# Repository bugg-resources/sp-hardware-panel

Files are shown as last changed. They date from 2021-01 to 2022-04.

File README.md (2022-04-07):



# sp-hardware-panel

This repository contains the KiCad source files for the panelled version of the PCBs required for the Bugg recording device (``main``, ``led``, and ``mic``). 

Also hosted here is the itemised BoM for the whole project.

For a full overview of the design of the Bugg recording device and practical assembly instructions please refer to the [Bugg hardware handover document](https://raw.githubusercontent.com/bugg-resources/bugg-handover/master/bugg-handover.pdf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).

Bugg PCBs panelled together

## Electronics overview

Bugg full assembly - side

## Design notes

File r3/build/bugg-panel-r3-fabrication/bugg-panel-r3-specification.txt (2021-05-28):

Panel
-----
Design stepped 4-up with 5mm borders for machine handling.
Please note the marked area where no mouse bites or supports may be present.
Please provide panel design for review before fabrication.

Quantity: 20 panels (80 units).

PCB specification
-----------------
Material: 4-layer, 1.6mm, 35um copper, FR4.
Stack-up not critical - example could be:
1-2  0.22mm
2-3  1.00mm
3-4  0.22mm
Soldermask: matte black preferred, gloss black ok.
Silkscreen: white, top side only.
Finish: ENIG

Layer order
-----------
F.Cu - top side
In1.Cu - inner 1 (gnd)
In2.Cu - inner 2
B.Cu - bottom side

Contact
-------
Invoice to:
Jeff Gough
Monad Gottfried Ltd.
3 Essex Park Mews, London
purchase@monad.is
+447903005844

Delivery to:
Likely direct to HCD. To be confirmed.

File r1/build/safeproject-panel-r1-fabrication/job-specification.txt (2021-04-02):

Project
-------
safeproject-panel-r1

PCB specification
-----------------
Material: 2-layer, 1.6mm, FR4, ENIG or other planar finish
Soldermask: white preferred, or green if it's quicker
Silkscreen: black / white, top side only

Mechanical
----------
Feel free to add extra framing if the mousebites are too flimsy

Stack-up
--------
F.Cu - top side
B.Cu - bottom side

Assembly
--------
none

Contact
-------
Invoice to:
Jeff Gough
Monad Gottfried Ltd.
3 Essex Park Mews, London
purchase@monad.is
+447903005844

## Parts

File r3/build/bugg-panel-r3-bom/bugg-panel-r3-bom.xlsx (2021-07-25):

Designator | Package | Qty/PCBA | Value | Rating | Manufacturer | MPN | Mouser | Digikey | Farnell | RS | LCSC | Re-reel: M/D/no | Min Qty | Qty to order | Rcvd.prod | Pkg | Unit GBP/100 | Line GBP | Status / best bet | Select source | Description | Substitute | Notes
BT1 | Keystone-3000-CR1220-CR1216 | 1 | CR1220 |  | Keystone | 3000TR | 534-3000TR | 36-3000CT-ND |  |  |  |  | 85 | 100 | 100 |  |  |  |  | M
C105,C101,C107,C111,C109 | C_0402_1005Metric | 5 | 100nF | 6.3V | Murata | GRM155R71H104KE4D | 81-GRM155R71H104KE4D |  |  |  | C1525 |  | 425 | 500 | 500 |  |  |  |  | L
C103,C102,C106 | C_0402_1005Metric | 3 | 1uF | 6.3V | Murata | GRM155C81C105KE5D | 81-GRM155C81C105KE5D |  |  |  | C107372 |  | 255 | 500 | 500 |  |  |  |  | L
C104,C108,C110 | C_0603_1608Metric | 3 | 10uF | 6.3V | Samsung | CL10A106MQ8NNNC | 187-CL10A106MQ8NNNC |  |  |  | C1691 |  | 255 | 1000 | 1000 |  |  |  |  | L
C11 | C_0603_1608Metric | 1 | 18pF |  | Samsung | CL10C180JB8NNNC | 187-CL10C180JB8NNNC |  |  |  | C1647 |  | 85 | 500 | 500 |  |  |  |  | L
C12,C21 | C_0603_1608Metric | 2 | 15pF |  | Samsung | CL10C150JB8NNNC | 187-CL10C150JB8NNNC |  |  |  | C1644 |  | 170 | 500 | 600 |  |  |  |  | L
C13,C16,C15,C14 | C_1206_3216Metric | 4 | 47uF | 6.3V | Murata | GRM31CE70J476ME5L | 81-GRM31CE70J476ME5L |  | 1907351 |  |  |  | 340 | 400 | 500
C20,C19 | C_0402_1005Metric | 2 | DNP |  |  |  |  |  |  |  |  |  | 0 | 0
C23,C22,C29 | C_0805_2012Metric | 3 | 47uF | 6.3V | Samsung | CL21A476MQYNNNE | 187-CL21A476MQYNNNE |  |  |  | C16780 |  | 255 | 500 | 500 |  |  |  |  | L
C24 | C_0805_2012Metric | 1 | DNP 4.7uF |  |  |  |  |  |  |  |  |  | 0
C28 | C_0603_1608Metric | 1 | 1nF |  | Samsung | CL10B102KC8NNNC | 187-CL10B102KC8NNNC |  |  |  | C153291 |  | 85 | 500 | 500 |  |  |  |  | L
C36,C18,C17,C38,C30,C10,C32,C35,C9,C33,C39,C26,C34,C37 | C_0603_1608Metric | 14 | 100nF |  | Samsung | CL10B104KB8NNNC | sub: 187-CL10B104KB85PNL |  |  |  | C1591 |  | 1190 | 4000 | 4000 |  |  |  |  | L
C42,C41,C4,C3,C1 | C_0603_1608Metric | 5 | 220nF | 50V | Samsung | CL10B224KB8NNNC | 187-CL10B224KB8NNNC |  |  |  | C64705 |  | 425 | 600 | 700 |  |  |  |  | L
C112,C40,C7,C31,C8 | C_0603_1608Metric | 5 | 1uF |  | Samsung | CL10B105KO8NNNC | sub:187-CL10B105KO8VPNC |  |  |  | C59782 |  | 425 | 1000 | 1000 |  |  |  |  | L
C43,C45,C6,C5,C2,C44 | C_1206_3216Metric | 6 | 4.7uF | 50V | Samsung | CL31B475KBHNNNE |  |  |  |  | C51205 |  | 510 | 700 | 700 |  |  |  |  | L
D1 | CHIPLED-0805 | 1 | LG R971-KN-1 |  | Osram | LGR971-KN-1 | 720-LGR971-KN-1 | 475-1410-6-ND |  |  |  | DM | 85 | 100 | 100 |  | 0.05 |  | Stock OK | M
D2 | CHIPLED-0805 | 1 | LH R974-LP-1 |  | Osram | LHR974-LP-1 | 720-LHR974-LP-1 | 475-1415-6-ND |  |  |  | DM | 85 | 100 | 100 | reel | 0.05 |  | Stock OK | M
D3 | CHIPLED-0805 | 1 | LO R976-PS-1 |  | Osram | LOR976-PS-1 | 720-LOR976-PS-1 | 475-2488-6-ND |  |  |  | DM | 85 | 100 | 100 | reel | 0.05 |  | Stock OK | M
D4 | D_SOD-123 | 1 | ATV02W360B-HF |  | Comchip | ATV02W360B-HF | 750-ATV02W360B-HF | 641-1664-6-ND |  |  |  | DM | 85 | 100 | 100 |  | 0.127 |  | Stock OK | M
D5 | D_SOD-123F | 1 | 12V |  | Diodes Inc. | BZT52C12-13-F | 621-BZT52C12-13-F | BZT52C1213-FDIDKR-ND |  |  |  | DM | 85 | 100 | 100 |  | 0.05 |  | Stock OK | M
D7 | CHIPLED-0805 | 1 | LY R976-PS-36 |  | Osram | LYR976-PS-36 | 720-LYR976-PS-36 | 475-2560-6-ND |  |  |  | DM | 85 | 100 | 100 |  | 0.05 |  | Stock OK | M
D6,D9 | D_0402_1005Metric | 2 | 0402ESDA-MLP1 |  | Eaton | 0402ESDA-MLP1 | 504-0402ESDA-MLP1 | 283-2964-6-ND |  |  |  | DM | 170 | 200 | 200 | reel | 0.12 |  | Stock OK | M
FB1,FB2 | L_1008_2520Metric | 2 | 1uH |  | Murata | LQM2HPN1R0MJHL | 81-LQM2HPN1R0MJHL | 490-12068-6-ND |  |  |  | DM | 170 | 200 | 200 | reel | 0.16 |  | Stock OK | M
J10 | Molex_CLIK-Mate_502443-0570_1x05-1MP_P2.00mm_Vertical | 1 | 502443-0560 |  | Molex | 502443-0560 | 538-502443-0560 |  |  |  |  |  | 85 | 85 | 85 |  |  |  |  | M
J101 | PinHeader_2x04_P2.00mm_Vertical_SMD_AMPMODU | 1 | 2842142-4 |  | TE | 2842142-4 | 571-2842142-4 | 17-2842142-4TR-ND |  |  |  | no | 85 | 100 | 100 | tape | 0.65 |  | Stock OK | M
J11 | SMA_Amphenol_132134-10_Vertical | 1 | DNP SMA |  | Amphenol | 132134-10 | 523-132134-10 | ARF2755-ND |  |  |  | bulk only | 0 | 0 |  |  | 4.62 |  | Stock OK | D | Fit only on test units
J12 | Coax_Conn_U.FL | 1 | U_FL-R-SMT-1_10_ |  | Cinch Johnson | 128-0711-201 | 530-1280711201 | J983DKR-ND |  |  |  | DM | 85 | 100 | 100 | reel | 0.29 |  | Stock OK | M
J13 | JAE_SIM_Card_SF72S006 | 1 | JAE_SIM_Card_SF72S006 |  | JAE | SF72S006VBDR2500 | 656-SF72S006VBDR2500 | 670-2967-6-ND |  |  |  | DM | 85 | 30 | 90 | reel | 1.07 |  | Stock OK | D | Memory Card Connectors NANO SIM Card |  | 60 in hand
J14 | microSD_JAE_ST11S008V4H | 1 | Micro_SD_Card_Det_JAE_ST11 |  | JAE | ST11S008V4HR2000 | 656-ST11S008V4HR2000 | 670-2695-6-ND |  |  |  | DM | 85 | 85 | 85 | reel | 1.37 |  | Stock OK | D | Memory Card Connectors microSD PUSH-PUSH HIGH RETENTION LOCK
J15 | USB_Micro-B_Amphenol_10118194_Horizontal | 1 | 10118194 |  | Amphenol | 10118194-0001LF | 649-10118194-0001LF | 609-4618-6-ND |  |  |  | DM | 85 | 100 | 100 | reel | 0.21 |  | Stock Med | M
J202,J16 | Hirose_FH12-20S-0.5SH_1x20-1MP_P0.50mm_Horizontal | 2 | FH12A-20S-0.5SH |  | Hirose | FH12A-20S-0.5SH(55) | 798-FH12A-20S0.5SH55 | HFK120CT-ND |  |  |  | DM | 170 | 170 | 170 | reel | 0.84 |  | Stock OK | D
J201 | PinSocket_2x04_P2.00mm_Vertical_SMD_Bottom_or_Top_Entry_AMPMODU | 1 | 2314844-8 |  | TE | 2314844-8 | 571-2314844-8 | 17-2314844-8-ND |  |  |  | tube only | 85 | 85 | 85 | tube | 0.42 |  | Stock OK | D | 8 Position Receptacle, Bottom or Top Entry Connector 0.079" (2.00mm) Surface Mount Gold
L1 | L_Coilcraft_XAL5030 | 1 | 4.7uH |  | Coilcraft | XAL5030-472 | 994-XAL5030-472MEB | no |  |  |  | M | 85 | 100 | 100 | reel | 1.45 |  | Stock OK | M | Fixed Inductors 4.7uH Shld 20% 5.9A 36mOhms AECQ2
L2 | L_Coilcraft_XAL5030 | 1 | 3.3uH |  | Coilcraft | XAL5030-332 | 994-XAL5030-332MEB | no |  |  |  | M | 85 | 100 | 100 | reel | 1.45 |  | Stock OK | M | Fixed Inductors 3.3uH Shld 20% 8.1A 23.3mOhms AECQ2
LED203,LED202,LED201 | LED_Avago_PLCC4_3.2x2.8mm_CW | 3 | IN-P32TATRGB |  | Inolux | IN-P32TATRGB | 743-IN-P32TATRGB | 1830-1116-6-ND |  |  |  | DM | 255 | 260 | 260 | reel | 0.13 |  | Stock OK | M
MIC101 | Knowles_LGA-5_3.5x2.65mm | 1 | SPH0641LU4H-1 |  | Knowles | SPH0641LU4H-1 | 721-SPH0641LU4H-1 | SPH0641LU4H-1 |  |  |  | no stock | 80 |  | 82 |  | 0.98 |  | 82 in hand |  | MEMS Microphones DIG MEMs Mic, BP, Multimode,Ultrasonic
Module1 | Raspberry-Pi-4-Compute-Module-no-holes | 1 | ComputeModule4-CM4 |  | Raspberry Pi | CM4002016 |  |  | 3563481 |  |  |  | 70 | 70 | 70 | bulk | 31.01
Module1_connectors | DF40HC(3.0)-100DS-0.4v | 2 | DF40HC(3.0)-100DS-0.4v |  | Hirose | DF40HC(3.0)-100DS-0.4v | 798-DF40HC30100DS451 | H124602DKR-ND |  |  |  | DM | 170 | 170 | 170 |  | 1.52 |  | Stock OK | M
Q3,Q1,Q2 | Vishay_PowerPAK_1212-8_Single | 3 | Si7113ADN |  | Vishay | SI7113ADN-T1-GE3 | 78-SI7113ADN-T1-GE3 | SI7113ADN-T1-GE3DKR-ND |  |  |  | DM | 255 | 260 | 260 |  | 0.34 |  | Stock OK | M
Q11,Q9,Q4,Q10,Q8,Q7,Q6,Q5 | SOT-323_SC-70 | 8 | NX3008NBKW |  | Nexperia | NX3008NBKW,115 | 771-NX3008NBKW,115 | 1727-1280-6-ND |  |  |  | DM | 680 | 720 | 720 |  | 0.067 |  | Stock OK | M
R101,R102 | R_0402_1005Metric | 2 | 22R |  | Walsin | WR04X22R0FTL | 603-RC0402FR-0722RL |  |  |  | C163821 |  | 170 |  | 5000 |  |  |  |  | L
R18 | R_0402_1005Metric | 1 | DNP |  |  |  |  |  |  |  |  |  | 0 |  |  |  |  |  |  | DNP
R20,R19 | R_0402_1005Metric | 2 | 0R |  | Walsin | WR04X0000FTL | 603-RC0402JR-070RL |  |  |  | C163803 |  | 170 | 1000 | 1000 |  |  |  |  | L
R10,R9 | R_0603_1608Metric | 2 | 1M |  | Walsin | WR06X1004FTL | 603-RC0603FR-071ML |  |  |  | C163869 |  | 170 | 5000 | 5000 |  |  |  |  | L
R7,R8,R16,R13,R14,R12,R24,R11,R103 | R_0603_1608Metric | 9 | 100k |  | Walsin | WR06X1003FTL | 603-RC0603FR-07100KL |  |  |  | C132374 |  | 765 | 5000 | 5000 |  | 0.000869 |  |  | L
R17 | R_0603_1608Metric | 1 | 37.4k |  | Yageo | RC0603FR-0737K4L | RC0603FR-0737K4L |  |  |  | C163425 |  | 85 | 5000 | 5000 |  |  |  |  | L
R2,R3,R1 | R_0603_1608Metric | 3 | DNP |  |  |  |  |  |  |  |  |  | 0 | 0 |  |  |  |  |  | DNP
R201, R202, R203 | R_0603_1608Metric | 3 | 22k |  | RS PRO |  |  |  |  | 804-8952 |  |  | 255 | 5000 | 5000 |  |  |  |  | L | Decide on value for required LED brightness
R204, R205, R206 | R_0603_1608Metric | 3 | 39k |  | Yageo | AC0603FR-0739KL |  |  |  | 197-8062 |  |  | 255 | 5000 | 5000
R22 | R_0603_1608Metric | 0 | DNP 15k |  |  |  |  |  |  |  |  |  | 0 |  |  |  |  |  |  | DNP
R23 | R_0603_1608Metric | 1 | 0R |  | Walsin | WR06X0000FTL | 603-RC0603JR-070RL |  |  |  | C163836 |  | 85 | 5000 | 5000 |  |  |  |  | L
R26,R15,R27,R25 | R_0603_1608Metric | 4 | 23.7k |  | Walsin | WR06X2372FTL | 603-RC0603FR-0723K7L |  |  |  | C168293 |  | 340 | 5000 | 5000 |  |  |  |  | L
R30,R29 | R_0603_1608Metric | 2 | 510k |  | Walsin | WR06X5103FTL | 603-RC0603FR-07510KL |  |  |  | C163930 |  | 170 | 5000 | 5000 |  |  |  |  | L
R35,R36 | R_0603_1608Metric | 2 | 0.1R |  | Uni-Royal | 0603WAJ010KT5E | 603-RL0805JR070R1L |  |  |  | C247025 |  | 170 | 5000 | 5000 |  |  |  |  | L
R44,R5,R4,R34,R28,R31,R32 | R_0603_1608Metric | 7 | 1k |  | Walsin | WR06X1001FTL | 603-RC0603FR-071KL |  |  |  | C112433 |  | 595 | 5000 | 5000 |  |  |  |  | L
R43,R40,R38,R33,R45,R37,R6,R21,R41,R39,R42,R46, R207, R208, R209 | R_0603_1608Metric | 15 | 10k |  | Yageo | 603-RC0603FR-1310KL | 603-RC0603FR-1310KL |  |  |  |  |  | 1275 | 2000 | 2500 |  |  |  |  | M
H101,H102 | Mounting_Wuerth_WA-SMSI-M3_H7mm_9774070360 | 2 | wurth-spacer-WA-SMSI-9774070360 |  | Wurth | 9774070360R | 710-9774070360R | 732-5274-1-ND |  |  |  | Not worth it | 170 | 170 | 169 | reel |  |  | Dk:69 Fn: 51 Sample:30! | DFW
SP3,SP1,SP2,SP4 | wurth-spacer-WA-SMSI-9774030151R | 4 | wurth-spacer-9774030151R |  | Wurth | 9774030151R | 710-9774030151R | 732-7083-6-ND |  |  |  | DM | 340 | 340 | 372 | reel | 0.53 |  | Stock OK | D
U14,U1 | SOT-353_SC-70-5 | 2 | 74LVC1G07DCK |  | TI | SN74LVC1G07DCKT | 595-SN74LVC1G07DCK3 | 296-26591-6-ND |  |  |  | DM | 170 | 170 | 170 | reel | 0.18 |  | Stock OK | M
U101 | QFN-24-1EP_4x4mm_P0.5mm_EP2.65x2.65mm_ThermalVias | 1 | PCMD3180 |  | TI | PCMD3180IRTWT | 595-PCMD3180IRTWT | 296-PCMD3180IRTWTDKR-ND |  |  |  | no | 85 | 100 | 100 | tape | 2.84 |  | Low stock – Mouser only | M
U12 | QFN-24-1EP_4x4mm_P0.5mm_EP2.6x2.6mm | 1 | CP2102N-Axx-xQFN24 |  | Si Labs | CP2102N-A02-GQFN24R | 634-CP2102NA02QFN24R | 336-5888-6-ND |  |  | C969151 | no | 85 | 100 | 95 |  |  |  | Only stock at LCSC | L
U13 | SOIC-8_3.9x4.9mm_P1.27mm | 1 | DS3231MZ |  | Maxim | DS3231MZ+ | 700-DS3231MZ+ | DS3231MZ+-ND |  |  |  | no | 85 | 85 | 85 | tube | 4.3 |  | Only tubes available | D
U15 | MSOP-10_3x3mm_P0.5mm | 1 | FSUSB42MX |  | On Semi | FSUSB42MUX | 512-FSUSB42MUX | FSUSB42MUXDKR-ND |  |  | C11355 | no | 85 | 100 | 95 |  | 0.52 |  | Only stock at LCSC | L
U9 | SSOP-20_4.4x6.5mm_P0.65mm | 1 | PCF8574PW |  | TI | PCF8574PW | 595-PCF8574PWG4 |  |  |  |  |  | 85 | 85 | 85
U8,U11,U10,U2,U16 | USON-10_2.5x1.0mm_P0.5mm | 5 | ESD7004 |  | On Semi | ESD7004MUTAG | 863-ESD7004MUTAG | ESD7004MUTAGOSDKR-ND |  |  |  | DM | 425 | 500 | 500 | reel | 0.16 |  | Mousereel | M
U3,U4 | SOT-363_SC-70-6 | 2 | DZDH0401DW |  | Diodes Inc. | DZDH0401DW | DZDH0401DW-7 | 31-DZDH0401DW-7DKR-ND |  |  |  | D | 170 | 170 | 170 | reel | 0.15 |  | Stock OK | D
U5,U6 | WQFN-HR-13 | 2 | LM60440DRPK |  | TI | LM60440DRPK | 595-LM60440DRPKR | 595-LM60440DRPKR |  |  |  | D | 170 | 170 | 170 | reel | 1.4 |  | Stock OK | D
U7 | Cellular_Modem-Sierra-Wireless-module-CF3-ringCD | 1 | Sierra_Wireless_RC7620 |  | Sierra Wireless | RC7620 |  |  |  |  |  | Reeled | 76 | 76 | // |  |  |  | In hand
 |  |  |  |  |  |  |  |  |  |  |  |  | 0
 |  |  |  |  |  |  |  |  |  |  |  |  | 0
Light pipes |  | 3 | 1282.1501 |  | Mentor | 1282.1501 |  |  | 2300599 |  |  |  | 255 | 300 | 277 |  | 1.16 |  | Stock OK | F
Thumbscrews |  |  |  |  | Automotion | P0161.030-010-B2 |  |  |  |  |  |  | 0
Locking washers |  |  |  |  | Automotion | P0168.030-A2 |  |  |  |  |  |  | 0
Molex Clik-Mate crimp contact |  | 5 |  |  | Molex | 502438-0100 | 538-502438-0100 |  |  |  |  |  | 425 | 500 | 500 |  |  |  |  | M
Molex Clik-Mate housing |  |  |  |  | Molex | 502439-0500 | 538-502439-0500 |  |  |  |  |  | 85 | 100 | 100 |  |  |  |  | M
M12 receptacle panel mount A coding |  |  |  |  | TE | T4171310005-001 | 571-T4171310005-001 |  |  |  |  |  | 75 | 85 | 78 |  | 5.80 |  | Low stock | M
M12 plug cable mount A coding PG7 |  |  |  |  | TE | T4111001051-000 | 571-T4111001051-000 |  |  |  |  |  |  |  |  |  |  |  |  | M
Cable for M12 flying power leads 1.5m
Cable for USB debug (USB 2.0 A-to-bare end) |  | 1 |  |  | Stewart Connector | SC-2ADK003F | 530-SC-2ADK003F |  |  |  |  |  | 10 | 10 | 10 |  | 1.31 |  |  | M
Acoustic membrane |  | 1 |  |  | Voir |  |  |  |  |  |  |  | 85 |  | 100 |  |  |  |  | Voir
Screw 3x8mm Pan head Torx drive T10 self tap A2 SS Plastech-30 |  | 6 |  |  | TR Fastenings | TR00032288-000 |  |  |  |  |  |  | 510 | 1000 | 1000 |  |  |  |  | TR
Screw M3x8mm Pan head Torx drive T10 machine screw A2 SS |  | 6 |  |  | TR Fastenings | TR00009928-000 |  |  |  |  |  |  | 510 | 1000 | 1000 |  |  |  |  | TR
Screw M2.5x4mm
FFC’s |  | 1 |  |  | Wurth | 687720100002 |  |  |  |  |  |  | 85 |  |  |  |  |  |  | M | FFC / FPC Jumper Cables WR-FFC 0.5mm Type 2 20P 100mm length. Opposide side contacts
CR1220 coin cell |  | 1 |  |  |  |  |  |  |  |  |  |  | 85
Antenna |  | 1 |  |  | Taoglas | FXUB63.07.0150C | 960-FXUB63.07.0150C |  |  |  |  |  | 80 | 80 |  |  |  |  |  | M
 |  |  |  |  |  |  |  |  |  |  |  |  | 0
 |  |  |  |  |  |  |  |  |  |  |  |  | 0
 |  |  |  |  |  |  |  |  |  |  |  |  | 0
 | USD-GBP | 1.38
Prototype units (r2) | 8
Production units (r3) | 70
Production units plus spare parts | 85
Prices exclude re-reeling fees | elieve
Order from LCSC
Order from Mouser
Order from Digikey
Order from Farnell
Order from RS
Order from Manufacturer (See Manufacturer column)
In hand
DNP

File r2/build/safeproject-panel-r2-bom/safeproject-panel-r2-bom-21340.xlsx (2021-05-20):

Id | Designator | Package | Qty/PCBA | Proto qty | Value | Rating | Manufacturer | MPN | Mouser | Digikey | Farmell | LCSC | Re-reel: M/D/no | Min Qty | Qty to order | Rcvd.prod | Pkg | Rcvd. proto | Unit GBP/100 | Line GBP | Status / best bet | Select source | Description | Substitute | Notes
66 | BT1 | Keystone-3000-CR1220-CR1216 | 1 | 8 | CR1220 |  | Keystone | 3000TR | 534-3000TR | 36-3000CT-ND |  |  |  | 85 | 100 | 100 |  | 8 |  |  |  | M
1 | C101,C107,C111,C109,C105 | C_0402_1005Metric | 5 | 40 | 100nF | 6.3V | Samsung | CL05B104KO5NNNC | 187-CL05B104KO5NNNC |  |  | C1525 |  | 425 | 100 |  |  | 40 |  |  |  | L | Don’t order a reel – this part will be 0603 in rev 3.
58 | C103,C102,C106,C112 | C_0402_1005Metric | 4 | 32 | 1uF | 6.3V | Samsung | CL05A105KQ5NNNC | 187-CL05A105KQ5NNNC |  |  | C107372 |  | 340 | 100 |  |  | 32 |  |  |  | L | Don’t order a reel – this part will be 0603 in rev 3.
29 | C108,C104,C110 | C_0603_1608Metric | 3 | 24 | 10uF | 6.3V | Samsung | CL10A106MQ8NNNC | 187-CL10A106MQ8NNNC |  |  | C1691 |  | 255 | 1000 |  |  | 24 |  |  |  | L
71 | C11 | C_0603_1608Metric | 1 | 8 | 18pF |  | Samsung | CL10C180JB8NNNC | 187-CL10C180JB8NNNC |  |  | C1647 |  | 85 | 500 |  |  | 10 |  |  |  | L
42 | C12,C21 | C_0603_1608Metric | 2 | 16 | 15pF |  | Samsung | CL10C150JB8NNNC | 187-CL10C150JB8NNNC |  |  | C1644 |  | 170 | 500 |  |  | 16 |  |  |  | L
22 | C14,C16,C15,C13 | C_1206_3216Metric | 4 | 32 | 47uF | 6.3V |  |  |  |  | 1907351 |  |  | 340 | 500 | 500 |  |  |  |  |  |  | Consider change to 0805 to match C22, C23 etc
56 | C19,C20 | C_0402_1005Metric | 0 | 0 | DNP |  |  |  |  |  |  |  |  | 0
41 | C23,C29,C22 | C_0805_2012Metric | 3 | 24 | 47uF | 6.3V | Samsung | CL21A476MQYNNNE | 187-CL21A476MQYNNNE |  |  | C16780 |  | 255 | 500 |  |  | 24 |  |  |  | L
34 | C24 | C_0805_2012Metric | 1 | 0 | DNP 4.7uF |  |  |  |  |  |  |  |  | 85
24 | C28 | C_0603_1608Metric | 1 | 8 | 1nF |  | Samsung | CL10B102KC8NNNC | 187-CL10B102KC8NNNC |  |  | C153291 |  | 85 | 500 |  |  | 10 |  |  |  | L
10 | C35,C26,C17,C18,C36,C38,C37,C33,C30,C39,C27,C9,C32,C10,C25,C34 | C_0603_1608Metric | 16 | 128 | 100nF |  | Samsung | CL10B104KB8NNNC | sub: 187-CL10B104KB85PNL |  |  | C1591 |  | 1360 | 4000 |  |  | 128 |  |  |  | L
20 | C4,C42,C1,C3,C41 | C_0603_1608Metric | 5 | 40 | 220nF | 50V | Samsung | CL10B224KB8NNNC | 187-CL10B224KB8NNNC |  |  | C64705 |  | 425 | 600 |  |  | 40 |  |  |  | L
19 | C40,C7,C31,C8 | C_0603_1608Metric | 4 | 32 | 1uF |  | Samsung | CL10B105KO8NNNC | sub:187-CL10B105KO8VPNC |  |  | C59782 |  | 340 | 1000 |  |  | 32 |  |  |  | L
8 | C45,C43,C44,C6,C2,C5 | C_1206_3216Metric | 6 | 48 | 4.7uF | 50V | Samsung | CL31B475KBHNNNE |  |  |  | C51205 |  | 510 | 700 |  |  | 48 |  |  |  | L
64 | D1 | CHIPLED-0805 | 1 | 8 | LG R971-KN-1 |  | Osram | LGR971-KN-1 | 475-1410-6-ND | 475-1410-6-ND |  |  | DM | 85 | 100 | 100 |  | 10 | 0.05 |  | Stock OK | M
65 | D2 | CHIPLED-0805 | 1 | 8 | LH R974-LP-1 |  | Osram | LHR974-LP-1 | 720-LHR974-LP-1 | 475-1415-6-ND |  |  | DM | 85 | 100 | 100 | reel | 10 | 0.05 |  | Stock OK | M
54 | D3 | CHIPLED-0805 | 1 | 8 | LO R976-PS-1 |  | Osram | LOR976-PS-1 | 720-LOR976-PS-1 | 475-2488-6-ND |  |  | DM | 85 | 100 | 100 | reel | 10 | 0.05 |  | Stock OK | M
44 | D4 | D_SOD-123 | 1 | 8 | ATV02W360B-HF |  | Comchip | ATV02W360B-HF | 750-ATV02W360B-HF | 641-1664-6-ND |  |  | DM | 85 | 100 | 100 |  | 10 | 0.127 |  | Stock OK | M
74 | D5 | D_SOD-123F | 1 | 8 | 12V |  | Diodes Inc. | BZT52C12-13-F | 621-BZT52C12-13-F | BZT52C1213-FDIDKR-ND |  |  | DM | 85 | 100 | 100 |  | 10 | 0.05 |  | Stock OK | M
61 | D7 | CHIPLED-0805 | 1 | 8 | LY R976-PS-36 |  | Osram | LYR976-PS-36 | 720-LYR976-PS-36 | 475-2560-6-ND |  |  | DM | 85 | 100 | 100 |  | 10 | 0.05 |  | Stock OK | M
62 | D9,D6 | D_0402_1005Metric | 2 | 16 | 0402ESDA-MLP1 |  | Eaton | 0402ESDA-MLP1 | 504-0402ESDA-MLP1 | 283-2964-6-ND |  |  | DM | 170 | 200 | 200 | reel | 16 | 0.12 |  | Stock OK | M
55 | FB1,FB2 | L_1008_2520Metric | 2 | 16 | 1uH |  | Murata | LQM2HPN1R0MJHL | 81-LQM2HPN1R0MJHL | 490-12068-6-ND |  |  | DM | 170 | 200 | 200 | reel | 16 | 0.16 |  | Stock OK | M
30 | J10 | JST_PH_B5B-PH-SM4-TB_1x05-1MP_P2.00mm_Vertical | 1 | 8 | Conn_01x05_MountingPin |  | JST | B5B-PH-SM4-TBT(LF)(SN) | no | 455-3362-6-ND | 9491937 |  | D | 85 | 100 | 100 | reel |  | 0.49 |  | Stock OK | D
73 | J101 | PinHeader_2x04_P2.00mm_Vertical_SMD_AMPMODU | 1 | 8 | 2842142-4 |  | TE | 2842142-4 | 571-2842142-4 | 17-2842142-4TR-ND |  |  | no | 85 | 100 | 100 | tape | 10 | 0.65 |  | Stock OK | M
57 | J11 | SMA_Amphenol_132134-10_Vertical | 1 | 6 | SMA |  | Amphenol | 132134-10 | 523-132134-10 | ARF2755-ND |  |  | bulk only | 0 | 0 |  |  | 6 | 4.62 |  | Stock OK | D | Fit only on test units
33 | J12 | Coax_Conn_U.FL | 1 | 8 | U_FL-R-SMT-1_10_ |  | Cinch Johnson | 128-0711-201 | 530-1280711201 | J983DKR-ND |  |  | DM | 85 | 100 | 100 | reel | 10 | 0.29 |  | Stock OK | M
21 | J13 | JAE_SIM_Card_SF72S006 | 1 | 8 | JAE_SIM_Card_SF72S006 |  | JAE | SF72S006VBDR2500 | 656-SF72S006VBDR2500 | 670-2967-6-ND |  |  | DM | 85 | 30 | 30 | reel | 10 | 1.07 |  | Stock OK | D | Memory Card Connectors NANO SIM Card |  | 60 in hand
70 | J14 | microSD_JAE_ST11S008V4H | 1 | 8 | Micro_SD_Card_Det_JAE_ST11 |  | JAE | ST11S008V4HR2000 | 656-ST11S008V4HR2000 | 670-2695-6-ND |  |  | DM | 85 | 85 | 85 | reel | 10 | 1.37 |  | Stock OK | D | Memory Card Connectors microSD PUSH-PUSH HIGH RETENTION LOCK
38 | J15 | USB_Micro-B_Amphenol_10118194_Horizontal | 1 | 8 | 10118194-0001LF |  | Amphenol | 10118194-0001LF | 649-10118194-0001LF | 609-4618-6-ND |  |  | DM | 85 | 100 | 100 | reel | 10 | 0.21 |  | Stock Med | M
40 | J16, J202 | Hirose_FH12-20S-0.5SH_1x20-1MP_P0.50mm_Horizontal | 2 | 16 | FH12A-20S-0.5SH |  | Hirose | FH12A-20S-0.5SH(55) | 798-FH12A-20S0.5SH55 | HFK120CT-ND |  |  | DM | 170 | 170 | 170 | reel | 16 | 0.84 |  | Stock OK | D
43 | J201 | PinSocket_2x04_P2.00mm_Vertical_SMD_Bottom_or_Top_Entry_AMPMODU | 1 | 8 | 2314844-8 |  | TE | 2314844-8 | 571-2314844-8 | 17-2314844-8-ND |  |  | tube only | 85 | 85 | 85 | tube | 10 | 0.42 |  | Stock OK | D | 8 Position Receptacle, Bottom or Top Entry Connector 0.079" (2.00mm) Surface Mount Gold
72 | L1 | L_Coilcraft_XAL5030 | 1 | 8 | 4.7uH |  | Coilcraft | XAL5030-472 | 994-XAL5030-472MEB | no |  |  | M | 85 | 100 | 100 | reel | 8 | 1.45 |  | Stock OK | M | Fixed Inductors 4.7uH Shld 20% 5.9A 36mOhms AECQ2
47 | L2 | L_Coilcraft_XAL5030 | 1 | 8 | 3.3uH |  | Coilcraft | XAL5030-332 | 994-XAL5030-332MEB | no |  |  | M | 85 | 100 | 100 | reel | 8 | 1.45 |  | Stock OK | M | Fixed Inductors 3.3uH Shld 20% 8.1A 23.3mOhms AECQ2
36 | LED201,LED203,LED202 | LED_Avago_PLCC4_3.2x2.8mm_CW | 3 | 24 | IN-P32TATRGB |  | Inolux | IN-P32TATRGB | 743-IN-P32TATRGB | 1830-1116-6-ND |  |  | DM | 255 | 260 | 260 | reel | 24 | 0.13 |  | Stock OK | M
16 | MIC101 | Knowles_LGA-5_3.5x2.65mm | 1 | 8 | SPH0641LU4H-1 |  | Knowles | SPH0641LU4H-1 | 721-SPH0641LU4H-1 | SPH0641LU4H-1 |  |  | no stock | 85 |  |  |  | 10 | 0.98 |  | 82 in hand |  | MEMS Microphones DIG MEMs Mic, BP, Multimode,Ultrasonic
26 | Module1 | Raspberry-Pi-4-Compute-Module | 1 | 5 | ComputeModule4-CM4 |  | Raspberry Pi | CM4002016 |  |  | 3563481 |  |  | 85 | 70 | 65 | bulk | 5 | 31.01
 | Module1_connectors | DF40HC(3.0)-100DS-0.4v | 2 | 16 | DF40HC(3.0)-100DS-0.4v |  | Hirose | DF40HC(3.0)-100DS-0.4v | 798-DF40HC30100DS451 | H124602DKR-ND |  |  | DM | 170 | 170 |  |  | 16 | 1.52 |  | Stock medium | M
27 | Q2,Q3,Q1 | Vishay_PowerPAK_1212-8_Single | 3 | 24 | Si7113ADN |  | Vishay | SI7113ADN-T1-GE3 | 78-SI7113ADN-T1-GE3 | SI7113ADN-T1-GE3DKR-ND |  |  | DM | 255 | 260 | 260 |  | 24 | 0.34 |  | Stock OK | M
69 | Q4 | SOT-323_SC-70 | 1 | 8 | NX3008NBKW |  | Nexperia | NX3008NBKW,115 | 771-NX3008NBKW,115 | 1727-1280-6-ND |  |  | DM | 85 | 100 | 100 |  | 10 | 0.067 |  | Stock OK | M
52 | R101,R102 | R_0402_1005Metric | 2 | 16 | 22R |  | Walsin | WR04X22R0FTL | 603-RC0402FR-0722RL |  |  | C163821 |  | 170 |  |  |  | 16 |  |  |  | L | Don’t order a reel – this part will be 0603 in rev 3.
49 | R18 | R_0402_1005Metric | 0 | 0 | DNP |  |  |  |  |  |  |  |  | 0 |  |  |  |  |  |  |  | DNP
31 | R20,R19 | R_0402_1005Metric | 2 | 16 | 0R |  | Walsin | WR04X0000FTL | 603-RC0402JR-070RL |  |  | C163803 |  | 170 | 10000 |  |  | 16 |  |  |  | L
51 | R10,R9 | R_0603_1608Metric | 2 | 16 | 1M |  | Walsin | WR06X1004FTL | 603-RC0603FR-071ML |  |  | C163869 |  | 170 | 5000 |  |  | 16 |  |  |  | L
3 | R11,R12,R24,R8,R7,R13,R33,R16,R14,R103 | R_0603_1608Metric | 10 | 80 | 100k |  | Walsin | WR06X1003FTL | 603-RC0603FR-07100KL |  |  | C132374 |  | 850 | 5000 |  |  | 80 | 0.000869 |  |  | L
39 | R17 | R_0603_1608Metric | 1 | 8 | 37.4k |  | Yageo | RC0603FR-0737K4L | RC0603FR-0737K4L |  |  | C163425 |  | 85 | 5000 |  |  | 10 |  |  |  | L
28 | R2,R3,R1 | R_0603_1608Metric | 0 | 0 | DNP 0R |  |  |  |  |  |  |  |  | 0 |  |  |  |  |  |  |  | DNP
6 | R204,R201,R206,R203,R202,R205,R209,R207,R208 | R_0603_1608Metric | 9 | 72 | 22R |  | Walsin | WR06X22R0FTL | 603-RC0603FR-1022RL |  |  | C163887 |  | 765 | 5000 |  |  | 72 |  |  |  | L
59 | R21 | R_0603_1608Metric | 0 | 0 | DNP 29.4k |  |  |  |  |  |  |  |  | 0 |  |  |  |  |  |  |  | DNP
63 | R22 | R_0603_1608Metric | 0 | 0 | DNP 15k |  |  |  |  |  |  |  |  | 0 |  |  |  |  |  |  |  | DNP
25 | R23 | R_0603_1608Metric | 1 | 8 | 0R |  | Walsin | WR06X0000FTL | 603-RC0603JR-070RL |  |  | C163836 |  | 85 | 5000 |  |  | 10 |  |  |  | L
14 | R26,R15,R25,R27 | R_0603_1608Metric | 4 | 32 | 23.7k |  | Walsin | WR06X2372FTL | 603-RC0603FR-0723K7L |  |  | C168293 |  | 340 | 5000 |  |  | 32 |  |  |  | L
32 | R29,R30 | R_0603_1608Metric | 2 | 16 | 510k |  | Walsin | WR06X5103FTL | 603-RC0603FR-07510KL |  |  | C163930 |  | 170 | 5000 |  |  | 16 |  |  |  | L
50 | R35,R36 | R_0603_1608Metric | 2 | 16 | 0.1R |  | Uni-Royal | 0603WAJ010KT5E | 603-RL0805JR070R1L |  |  | C247025 |  | 170 |  |  |  | 16 |  |  |  | L | Error – ordered 0805 parts for prototype. Production ordered correctly
11 | R5,R6,R31,R32,R28,R4,R34 | R_0603_1608Metric | 7 | 56 | 1k |  | Walsin | WR06X1001FTL | 603-RC0603FR-071KL |  |  | C112433 |  | 595 | 5000 |  |  | 56 |  |  |  | L
15 | SP101,SP102 | wurth-spacer-WA-SMSI-9774070360R | 2 | 10 | WA-SMSI-9774070360R |  | Wurth | 9774070360R | 710-9774070360R | 732-5274-1-ND |  |  | Not worth it | 170 | 170 | 120 | reel | 10 |  |  | Dk:69 Fn: 51 Sample:30! | DFW
12 | SP3,SP2,SP1,SP4 | wurth-spacer-WA-SMSI-9774030151R | 4 | 32 | WA-SMSI-9774030151R |  | Wurth | 9774030151R | 710-9774030151R | 732-7083-6-ND |  |  | DM | 340 | 340 | 340 | reel | 32 | 0.53 |  | Stock OK | D
67 | U1,U14 | SOT-353_SC-70-5 | 2 | 16 | 74LVC1G07DCK |  | TI | SN74LVC1G07DCKT | 595-SN74LVC1G07DCK3 | 296-26591-6-ND |  |  | DM | 170 | 170 | 170 | reel | 16 | 0.18 |  | Stock OK | M
23 | U101 | QFN-24-1EP_4x4mm_P0.5mm_EP2.65x2.65mm_ThermalVias | 1 | 8 | PCMD3180 |  | TI | PCMD3180IRTWT | 595-PCMD3180IRTWT | 296-PCMD3180IRTWTDKR-ND |  |  | no | 85 | 100 | 100 | tape | 8 | 2.84 |  | Low stock – Mouser only | M
45 | U12 | QFN-24-1EP_4x4mm_P0.5mm_EP2.6x2.6mm | 1 | 8 | CP2102N-Axx-xQFN24 |  | Si Labs | CP2102N-A02-GQFN24R | 634-CP2102NA02QFN24R | 336-5888-6-ND |  | C969151 | no | 85 | 100 |  |  |  |  |  | Only stock at LCSC | L
35 | U13 | SOIC-8_3.9x4.9mm_P1.27mm | 1 | 8 | DS3231MZ |  | Maxim | DS3231MZ+ | 700-DS3231MZ+ | DS3231MZ+-ND |  |  | no | 85 | 85 | 85 | tube | 8 | 4.3 |  | Only tubes available | D
48 | U15 | MSOP-10_3x3mm_P0.5mm | 1 | 8 | FSUSB42MX |  | On Semi | FSUSB42MUX | 512-FSUSB42MUX | FSUSB42MUXDKR-ND |  | C11355 | no | 85 | 100 |  |  |  | 0.52 |  | Only stock at LCSC | L
5 | U17 | TSSOP-28_4.4x9.7mm_P0.65mm | 1 | 8 | PCA9685PW |  | NXP | PCA9685PW/Q900,118 | 771-PCA9685PWQ900118 | PCA9685PW/Q900,118 |  |  | DM | 85 | 88 | 88 | reel | 8 | 1.34 |  | 88 stock Mousereel | M
9 | U2,U11,U16,U8,U10 | USON-10_2.5x1.0mm_P0.5mm | 5 | 40 | ESD7004 |  | On Semi | ESD7004MUTAG | 863-ESD7004MUTAG | ESD7004MUTAGOSDKR-ND |  |  | DM | 425 | 500 | 500 | reel | 40 | 0.16 |  | Mousereel | M
37 | U3,U4 | SOT-363_SC-70-6 | 2 | 16 | DZDH0401DW |  | Diodes Inc. | DZDH0401DW | DZDH0401DW-7 | 31-DZDH0401DW-7DKR-ND |  |  | D | 170 | 170 | 170 | reel | 16 | 0.15 |  | Stock OK | D
68 | U6,U5 | WQFN-HR-13 | 2 | 16 | LM60440DRPK |  | TI | LM60440DRPK | 595-LM60440DRPKR | 595-LM60440DRPKR |  |  | D | 170 | 170 | 170 | reel | 16 | 1.4 |  | Stock OK | D
17 | U7 | Cellular_Modem-Sierra-Wireless-module-CF3-ringCD | 1 | 5 | Sierra_Wireless_RC7620 |  | Sierra Wireless | RC7620 |  |  |  |  | Reeled | 85 | 76 | 71 |  | 5 |  |  | In hand
53 | U9 | TSSOP-20_4.4x6.5mm_P0.65mm | 1 | 8 | TXS0108EPW |  | TI | TXS0108EPWR | 595-TXS0108EPWR | 296-23011-6-ND |  |  | DM | 85 | 100 |  |  | 8 | 0.7 |  | Stock OK | D
 |  |  |  |  |  |  |  |  |  |  |  |  |  | 0
 |  |  |  |  |  |  |  |  |  |  |  |  |  | 0
 | Light pipes |  | 3 |  | 1282.1501 |  | Mentor | 1282.1501 |  |  | 2300599 |  |  | 255 | 300 | 260 |  |  | 1.16 |  | Stock OK | F
 | Thumbscrews |  |  |  |  |  | Automotion | confirm 8 vs 10mm |  |  |  |  |  | 0
 | Snap rings? |  |  |  |  |  | Automotion | confirm necessary |  |  |  |  |  | 0
 | JST crimp contact |  | 5 |  |  |  | JST | SPH-002T-P0.5S |  |  |  |  |  | 425 | 500 | 500
 | JST housing |  |  |  |  |  | JST | PHR-5 |  |  |  |  |  | 0 | 100
 | M12 receptacle + flying leads |  |  |  |  |  | TE | T4171310005-001 | 571-T4171310005-001 |  |  |  |  | 0 | 80 |  |  |  | 5.80 |  | Low stock | M
 |  |  |  |  |  |  |  |  |  |  |  |  |  | 0
 |  | USD-GBP | 1.38
 | Prototype units (r2) | 8
 | Production units (r3) | 70
 | Production units plus spare parts | 85
 | Prices exclude re-reeling fees
 | Ordered from LCSC
 | Ordered from Mouser
 | Ordered from Digikey
 | Ordered from Farnell
 | In hand
 | DNP
 | Proto qty ordered

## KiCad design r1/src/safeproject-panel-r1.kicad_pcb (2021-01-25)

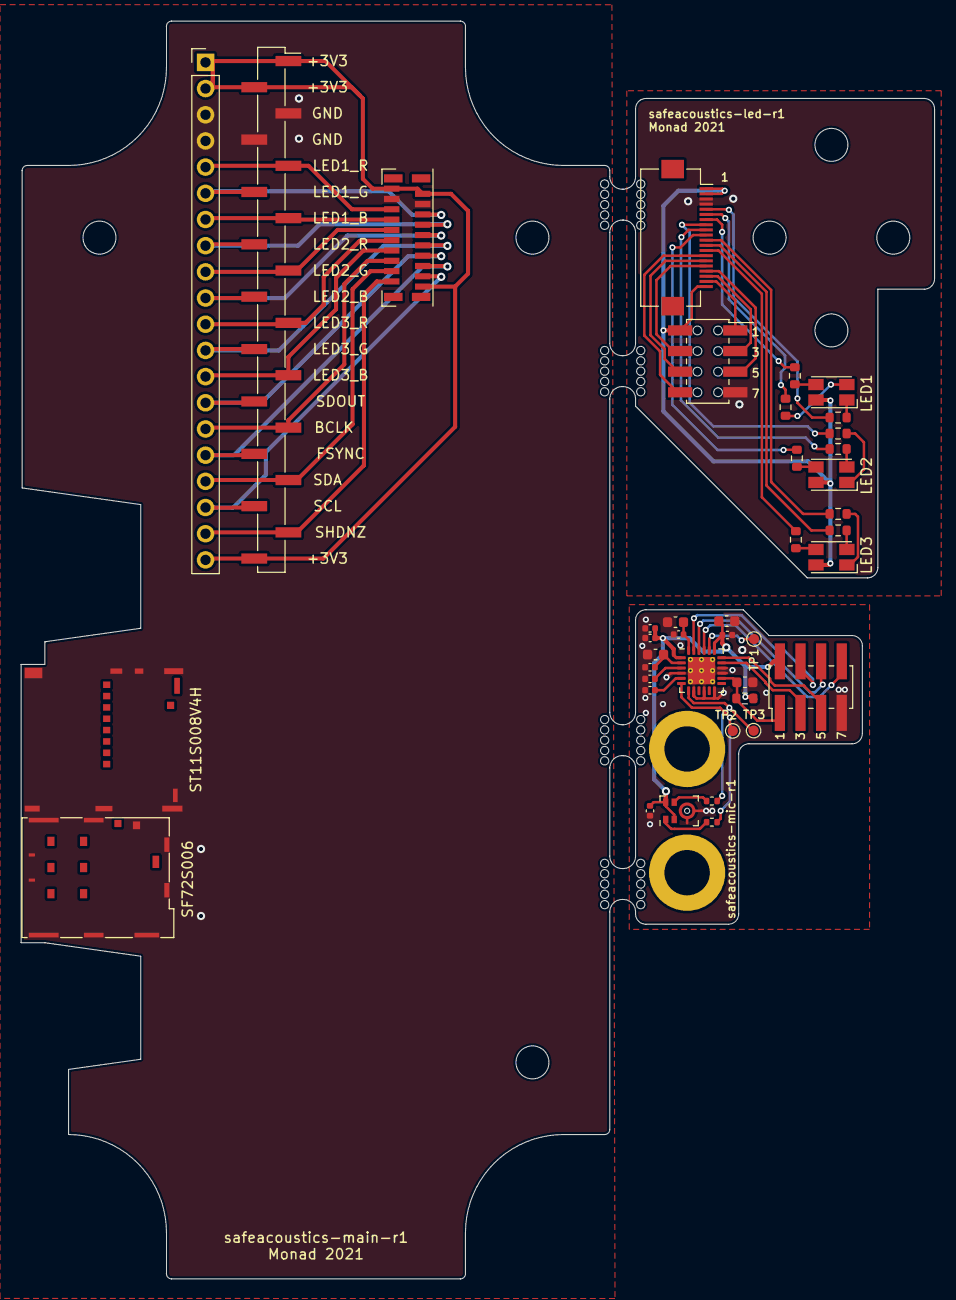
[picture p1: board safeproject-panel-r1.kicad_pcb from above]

Board: 2 copper layers, 88.6 x 122.0 mm, 40 parts (0 on the bottom side), 37 nets.

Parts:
C1, C5, C7, C9, C11: 100nF; C_0402_1005Metric
C2, C3, C6: 1uF; C_0402_1005Metric
C4, C8, C10, C12: 10uF; C_0603_1608Metric
J1: 2842142-4; PinSocket_2x04_P2.00mm_Vertical_SMD_Bottom_or_Top_Entry_AMP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
J1#2: JAE_SIM_Card_SF72S006
J1#3: 2842142-4; PinHeader_2x04_P2.00mm_Vertical_SMD_AMPMODU
J2: Conn_01x20; Hirose_FH12-20S-0.5SH_1x20-1MP_P0.50mm_Horizontal
J2#2: Conn_01x20; Hirose_FH12-20S-0.5SVA_1x20-1MP_P0.50mm_Vertical
J3: Micro_SD_Card_Det_JAE_ST11; microSD_JAE_ST11S008V4H
J4: Conn_01x20; PinHeader_1x20_P2.54mm_Vertical_SMD_Pin1Right
J5: Conn_01x20; PinHeader_1x20_P2.54mm_Vertical
LED1, LED2, LED3: IN-P32TATRGB; LED_Avago_PLCC4_3.2x2.8mm_CW
MK1: SPH0641LU4H-1; Knowles_LGA-5_3.5x2.65mm
R1, R2#2, R3, R4, R5, R6: 22R; R_0603_1608Metric
R1#2, R2: 22R; R_0402_1005Metric
R3#2: 10k; R_0603_1608Metric
R7, R8, R9: 100R; R_0603_1608Metric
TP1, TP2, TP3: TestPoint; TestPoint_Pad_D1.0mm
U1: PCMD3180; QFN-24-1EP_4x4mm_P0.5mm_EP2.65x2.65mm_ThermalVias

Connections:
+3V3: C1.1, C6.2, C7.2, C10.1, C11.1, J1.2, J1#3.2, J2.1, J2.2, J2.20, LED1.2 (A), LED2.2 (A), LED3.2 (A), MK1.2 (SEL), MK1.5 (VDD), R3#2.2, U1.1 (AVDD), U1.19 (IOVDD)
/+3V3: J2#2.1, J2#2.2, J2#2.20, J4.1, J4.2, J4.20, J5.1, J5.2, J5.20
/BCLK: J1.6, J1#3.6, J2.15, J2#2.15, J4.15, J5.15, U1.22 (BCLK)
/FSYNC: J1.4, J1#3.4, J2.16, J2#2.16, J4.16, J5.16, U1.23 (FSYNC)
/GND: J1#2.SH, J2#2.3, J2#2.4, J3.GND, J4.3, J4.4, J5.3, J5.4
/LED1_B: J2.7, J2#2.7, J4.7, J5.7, R1.1
/LED1_G: J2.6, J2#2.6, J4.6, J5.6, R4.1
/LED1_R: J2.5, J2#2.5, J4.5, J5.5, R7.1
/LED2_B: J2.10, J2#2.10, J4.10, J5.10, R2#2.1
/LED2_G: J2.9, J2#2.9, J4.9, J5.9, R5.1
/LED2_R: J2.8, J2#2.8, J4.8, J5.8, R8.1
/LED3_B: J2.13, J2#2.13, J4.13, J5.13, R3.1
/LED3_G: J2.12, J2#2.12, J4.12, J5.12, R6.1
/LED3_R: J2.11, J2#2.11, J4.11, J5.11, R9.1
/SCL: J1.3, J1#3.3, J2.18, J2#2.18, J4.18, J5.18, U1.17 (SCL_MOSI)
/SDA: J1.5, J1#3.5, J2.17, J2#2.17, J4.17, J5.17, U1.18 (SDA_SSZ)
/SDOUT: J1.8, J1#3.8, J2.14, J2#2.14, J4.14, J5.14, U1.21 (SDOUT)
/SHDNZ: C12.2, J1.1, J1#3.1, J2.19, J2#2.19, J4.19, J5.19, R3#2.1, U1.14 (SHDNZ)
GND: C1.2, C2.1, C3.1, C4.1, C5.1, C6.1, C7.1, C8.1, C9.1, C10.2, C11.2, C12.1, J1.7, J1#3.7, J2.3, J2.4, MK1.3 (GND), U1.4 (AVSS), U1.8 (PDMDIN2_GPI2), U1.10 (PDMDIN3_GPI3), U1.12 (PDMDIN4_GPI4), U1.15 (ADDR1_MISO), U1.16 (ADDR0_SCLK), U1.25 (VSS_THERMAL)
unnamed: C2.2, U1.5 (MICBIAS)
unnamed: C3.2, U1.3 (VREF)
unnamed: C4.2, C5.2, U1.2 (AREG)
unnamed: C8.2, C9.2, U1.24 (DREG)
unnamed: LED1.1 (RK), R7.2
unnamed: LED1.3 (BK), R1.2
unnamed: LED1.4 (GK), R4.2
unnamed: LED2.1 (RK), R8.2
unnamed: LED2.3 (BK), R2#2.2
unnamed: LED2.4 (GK), R5.2
unnamed: LED3.1 (RK), R9.2
unnamed: LED3.3 (BK), R3.2
unnamed: LED3.4 (GK), R6.2
unnamed: MK1.1 (DATA), R1#2.1
unnamed: MK1.4 (CLOCK), R2.1
unnamed: R1#2.2, TP2.1, U1.6 (PDMDIN1_GPI1)
unnamed: R2.2, TP3.1, U1.7 (PDMCLK1_GPO1)
unnamed: TP1.1, U1.20 (GPIO1)

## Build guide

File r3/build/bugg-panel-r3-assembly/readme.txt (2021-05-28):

Quantity
--------
We have 20 panels 4-up for a total of 80 units. However there may not be enough parts to populate all 80.
75 is the target.
70 is the bare minimum.

Placement info
--------------
Placement data:   bugg-panel-r3-assembly/bugg-panel-r3-top-pos.csv
Interactive bom:  bugg-panel-r3-bom/ibom.html (open in a web browser)
Full BoM:         bugg-panel-r3-bom/bugg-panel-r3-bom.xlsx
Assembly markers: bugg-panel-r3-fabrication/bugg-panel-r3-F_Fab.gbr

Contact
-------
Invoice to:
Jeff Gough
Monad Gottfried Ltd.
3 Essex Park Mews, London
purchase@monad.is
+447903005844

Delivery to:
------------
Jeff Gough
Monad Gottfried Ltd.
Flat 2, Tracey Court
239A Lymington Road
Highcliffe
Christchurch
BH23 5EB

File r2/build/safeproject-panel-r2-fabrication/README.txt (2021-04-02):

Stack up:

F_Cu
In1_Cu
In2_Cu
B_Cu

No silkscreen on back side.

Stencil per F_paste
No back side stencil.

Contact:
Jeff Gough
07903 005844
j@monad.is

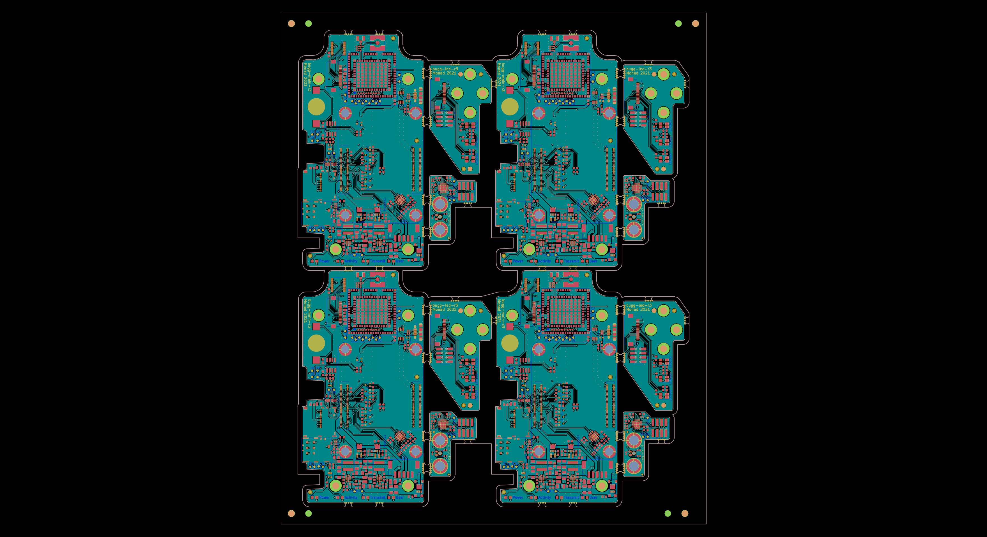
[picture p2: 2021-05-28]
r3/build/bugg-panel-r3-fabrication/screenbond-production-panel/screenbond-production-panel-r3.png

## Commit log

2021-01-25 Panel composed, mousebites in place
    [safeproject-panel-r1.kicad_pcb]
2021-01-25 DRC pass on panel
    [safeproject-panel-r1.kicad_pcb]
2021-04-01 Revised panel which should hopefully pass PCB train's DRC.
2021-04-02 Footprint table
2021-04-02 Tidy up board outline
2021-04-02 Fabrication data for r2 panel
    [safeproject-panel-r2-B_Cu.gbr, safeproject-panel-r2-B_Mask.gbr, safeproject-panel-r2-Edge_Cuts.gbr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]
2021-04-02 Fabrication data archive as issued to PCB Train
2021-04-02 r1 fabrication data
    [safeproject-panel-r1-B_Cu.gbr, safeproject-panel-r1-B_Mask.gbr, safeproject-panel-r1-B_Paste.gbr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]
2021-04-02 r1 stencil data as issued to PCB Train
2021-04-02 Interactive HTML bom created wtih the fancy Interactive Bom plugin
2021-04-03 Add 100 to mic designators and 200 to LED designators to prevent collisions and bring panel into parity with the individual sub-boards
2021-04-03 Set names of mounting holes and threaded spacers, and include them into the BoM appropriately. Exclude mousebites from BoM
2021-04-03 Exclude mousebites from Bom, attempt 2
2021-04-03 Correct value for LED FFC
2021-05-20 Tweak some resistor values. Unsure which!
2021-05-20 Remove redundant cad data archive
2021-05-23 Add jeffmakes-kicad-library as submodule
2021-05-26 Import BOM from r2, update with r3 changes. Checked all stock in hand, updated the Rcvd. Prod coloumn to reflect stock levels. Used data to order more stuff from Mouser
    [bugg-panel-r3-bom.xlsx]
2021-05-26 Add coin cells, FFC's
    [bugg-panel-r3-bom.xlsx]
2021-05-27 Update LED resistor values to make them less blinding
2021-05-27 CSV BOM export
    [bugg-panel-r3.csv]
2021-05-27 Update BOM to include more mechanical parts
    [bugg-panel-r3-bom.xlsx]
2021-05-27 Update BOM with correct LED resistor values
    [bugg-panel-r3-bom.xlsx]
2021-05-28 Add pin 1 marker to modem on F.Fab
2021-05-28 BOM update - check in some more parts
    [bugg-panel-r3-bom.xlsx]
2021-05-28 Interactive BoM
2021-05-28 Gerbers released for production
    [bugg-panel-r3-B_Cu.gbr, bugg-panel-r3-B_Mask.gbr, bugg-panel-r3-Edge_Cuts.gbr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]
2021-05-28 Remove intermediate CSV bom data so as not to confuse anyone
    [bugg-panel-r3.csv]
2021-05-28 Placement data and readme
    [bugg-panel-r3-top-pos.csv]
2021-05-28 Add assembly data to build archive
2021-07-25 Add a few more details to BoM
    [bugg-panel-r3-bom.xlsx]

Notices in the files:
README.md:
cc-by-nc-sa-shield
